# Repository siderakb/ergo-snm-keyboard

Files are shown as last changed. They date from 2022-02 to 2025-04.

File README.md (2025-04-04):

# ErgoSNM Keyboard







*ErgoSNM* \- a split ergonomic keyboard integrated with a trackball, designed to encourage people to leave their mouse behind.

- 64 keys in total.
    - Left half 29 + 6 keys.
    - Right half 29 keys + trackball.
- Cherry MX style switches, hot-swap available.
- USB Type-C.
- Column-staggered layout.
- The trackball can replace all mouse operations, allowing your right hand to stay on the *home row*.
    - Cursor movement and scrolling.
    - With the Combos feature:
        - *J*+*K* performs the left click
        - *K*+*L* performs the right click
        - *J*+*L* performs the middle click.

Introduction Video:

<a href="https://youtu.be/mWoAi_D721U" target="_blank">
  Thumbnail
</a>

| Rev | MCU | Note | Video |
| ----- | --- | --- | --- |
| `1.x` | Pro Micro (ATmega32U4) | Experimental version | |
| `2.x` | RaspberryPi **RP2040** | The first version suitable for daily use | [demo](https://youtu.be/1BXKdrCFn6c) |
| `3.x` | Nordic **nRF52840** (E73) | First wireless experimental version | [demo](https://www.youtube.com/watch?v=TtJiaOGiEaQ) |
| `4.x` | ??? | ⚡In progress | |

Build guide and more information can be found in the [📖Docs](https://siderakb.ziteh.dev/docs/ergosnm/intro)

## Clone

```bash
git clone --recurse-submodules https://github.com/siderakb/ergo-snm-keyboard.git
```

If `key-switches.pretty` folder is empty, run:

```bash
git submodule update --init --recursive
```

## Firmware

- Vial QMK: [siderakb/vial-qmk](https://github.com/siderakb/vial-qmk/tree/siderakb/main/keyboards/siderakb/ergosnm) (*siderakb/main* branch)
- nRF: [siderakb/ergo-snm-nrf-firmware](https://github.com/siderakb/ergo-snm-nrf-firmware)

## License

Hardware available under the [CERN-OHL-P v2](/LICENSE) permissive license.

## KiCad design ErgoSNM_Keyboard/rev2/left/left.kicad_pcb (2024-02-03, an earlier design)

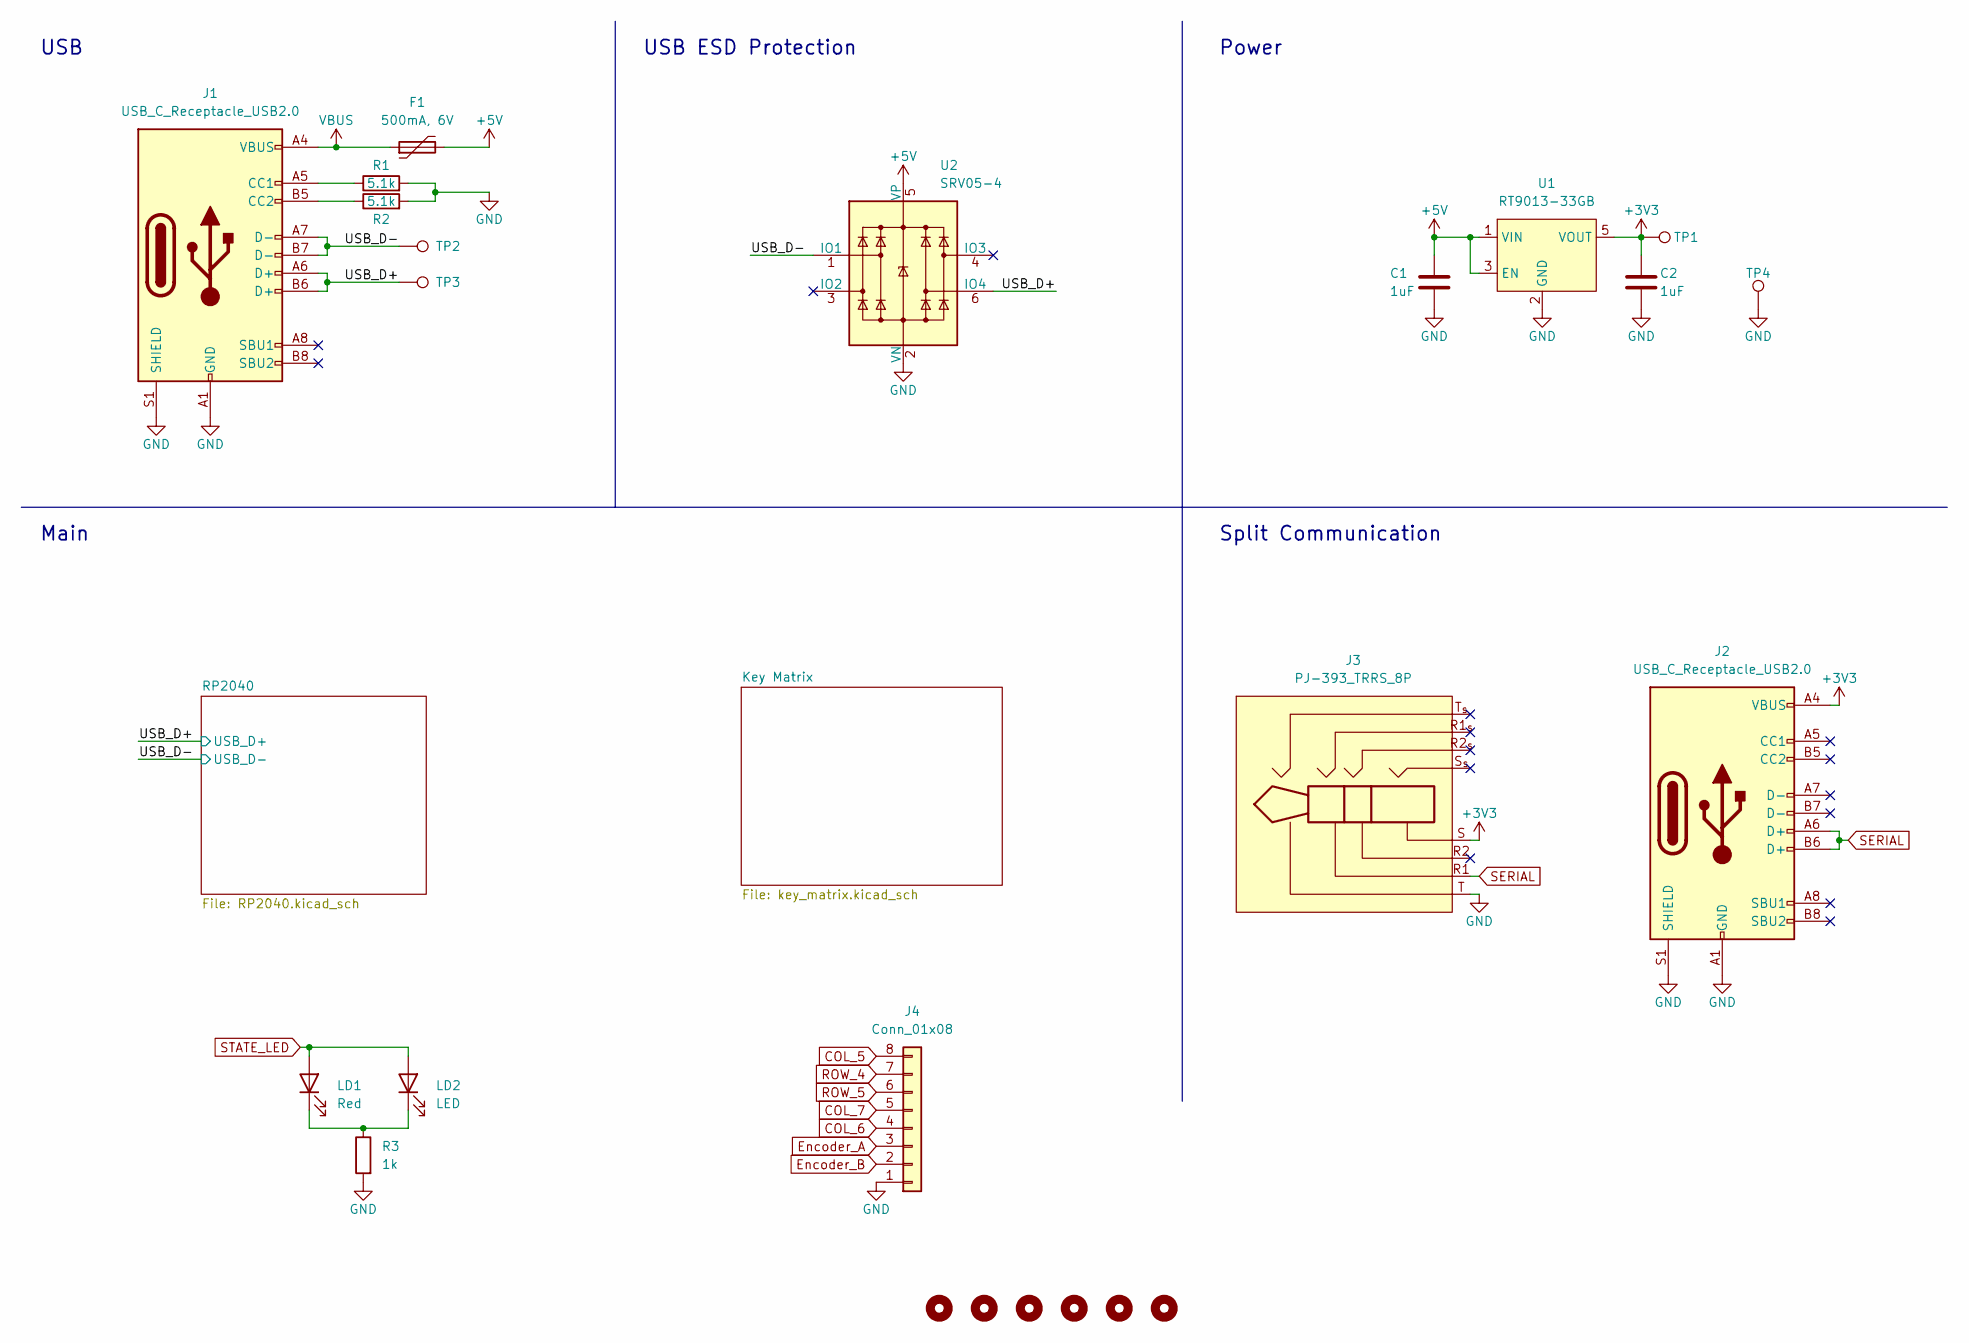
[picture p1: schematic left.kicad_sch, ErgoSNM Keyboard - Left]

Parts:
C1, C2: 1uF; C_0402_1005Metric; MFR. Part # CL05A105KA5NQNC; LCSC C52923
F1: 500mA, 6V; Fuse_0805_2012Metric; MFR. Part # SMD0805B050TF; LCSC C269104
H1, H2, H3, H4, H5, H6: MountingHole; MountingHole_2.2mm_M2
J1, J2: USB_C_Receptacle_USB2.0; USB_C_Receptacle_HRO_TYPE-C-31-M-12; MFR. Part # TYPE-C-31-M-12; LCSC C165948
J3: PJ-393_TRRS_8P; PJ-393 8P TRRS; MFR. Part # PJ-393 8PJ; LCSC C668609
J4: Conn_01x08; FPC_8P_0.5mm_AFC01-S08FCA-00; MFR. Part # SM08B-GHS-TB(LF)(SN); LCSC C265111
LD1: Red; LED_0603_1608Metric; MFR. Part # KT-0603R; LCSC C2286
LD2: LED; LED_0805_2012Metric_Pad1.15x1.40mm_HandSolder
R1, R2: 5.1k; R_0402_1005Metric; MFR. Part # 0402WGF5101TCE; LCSC C25905
R3: 1k; R_0402_1005Metric; MFR. Part # 0402WGF1001TCE; LCSC C11702
TP1, TP4: TestPoint; TestPoint_Pad_D2.5mm
TP2, TP3: TestPoint; TestPoint_Pad_D2.0mm
U1: RT9013-33GB; SOT-23-5; MFR. Part # RT9013-33GB; LCSC C47773
U2: SRV05-4; SOT-23-6; MFR. Part # SRV05-4-P-T7; LCSC C85364

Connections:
+3V3: C2.1, J2.A4 (VBUS), J2.A9 (VBUS), J2.B4 (VBUS), J2.B9 (VBUS), J3.S, TP1.1, U1.5 (VOUT); also elsewhere on the board
+5V: C1.1, F1.2, U1.1 (VIN), U1.3 (EN), U2.5 (VP)
/USB_D+: J1.A6 (D+), J1.B6 (D+), TP3.1, U2.6 (IO4); also elsewhere on the board
/USB_D-: J1.A7 (D-), J1.B7 (D-), TP2.1, U2.1 (IO1); also elsewhere on the board
COL_5: J4.8; also elsewhere on the board
COL_6: J4.4; also elsewhere on the board
COL_7: J4.5; also elsewhere on the board
Encoder_A: J4.3; also elsewhere on the board
Encoder_B: J4.2; also elsewhere on the board
GND: C1.2, C2.2, J1.A1 (GND), J1.A12 (GND), J1.B1 (GND), J1.B12 (GND), J1.S1 (SHIELD), J2.A1 (GND), J2.A12 (GND), J2.B1 (GND), J2.B12 (GND), J2.S1 (SHIELD), J3.T, J4.1, R1.2, R2.2, R3.2, TP4.1, U1.2 (GND), U2.2 (VN); also elsewhere on the board
unnamed: J1.A5 (CC1), R1.1
unnamed: J1.B5 (CC2), R2.1
unnamed: LD1.1 (K), LD2.1 (K), R3.1
ROW_4: J4.7; also elsewhere on the board
ROW_5: J4.6; also elsewhere on the board
SERIAL: J2.A6 (D+), J2.B6 (D+), J3.R1; also elsewhere on the board
STATE_LED: LD1.2 (A), LD2.2 (A); also elsewhere on the board
VBUS: F1.1, J1.A4 (VBUS), J1.A9 (VBUS), J1.B4 (VBUS), J1.B9 (VBUS)

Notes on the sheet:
Split Communication
USB ESD Protection
USB
Main
Power

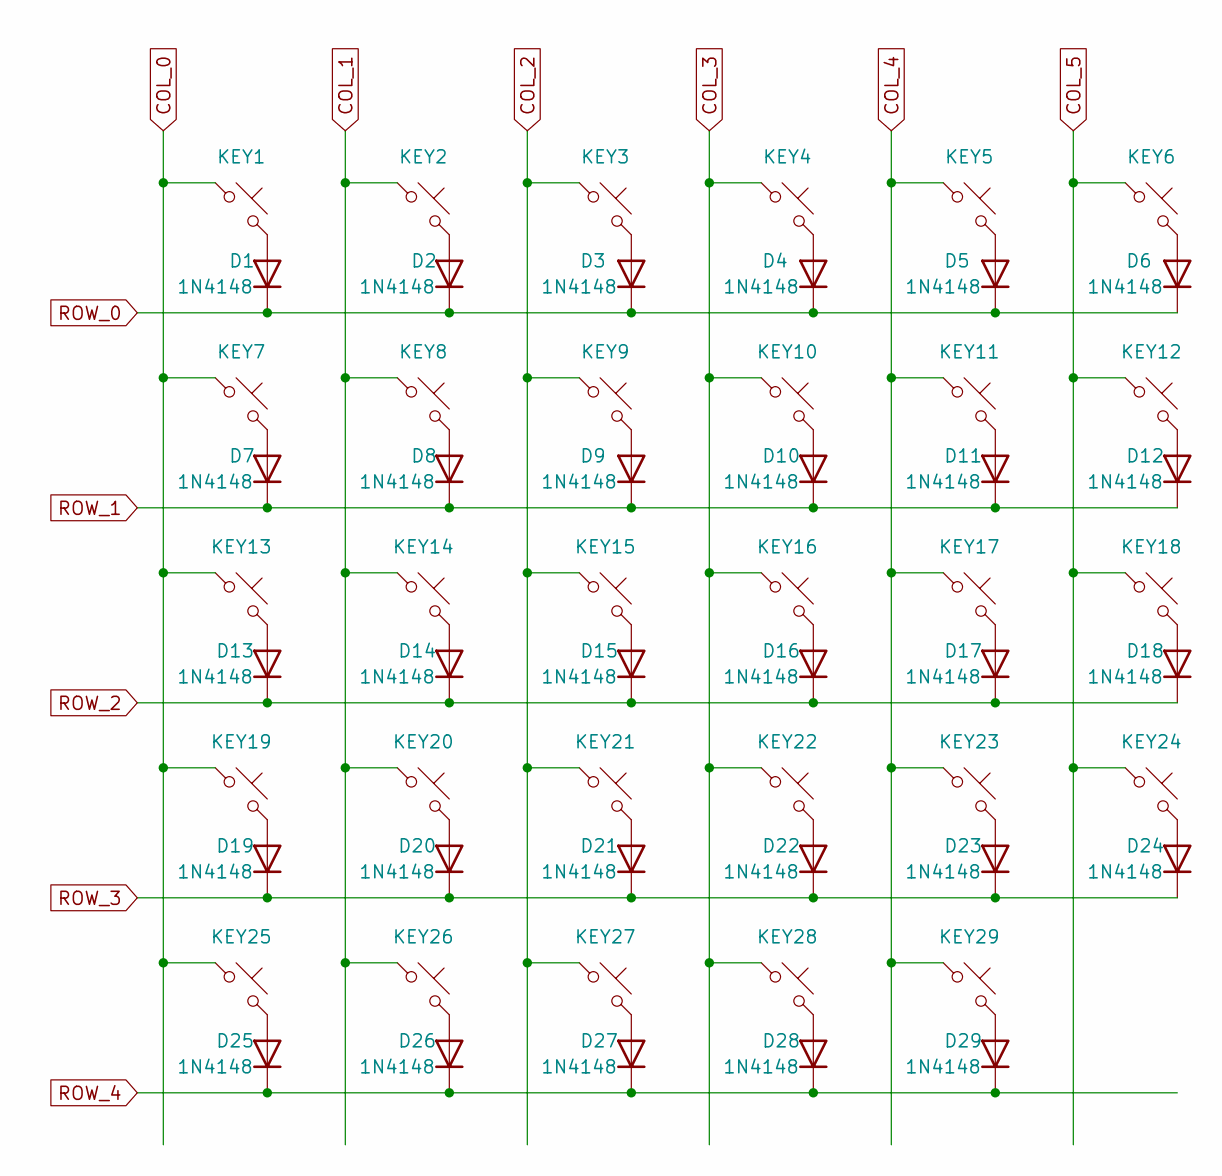
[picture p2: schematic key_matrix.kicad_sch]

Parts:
D1, D2, D3, D4, D5, D6, D7, D8, D9, D10, D11, D12, D13, D14, D15, D16, D17, D18, D19, D20, D21, D22, D23, D24, D25, D26, D27, D28, D29: 1N4148; D_SOD-123; MFR. Part # 1N4148W; LCSC C81598
KEY1, KEY2, KEY3, KEY4, KEY5, KEY6, KEY7, KEY8, KEY9, KEY10, KEY11, KEY12, KEY13, KEY14, KEY15, KEY16, KEY17, KEY18, KEY19, KEY20, KEY21, KEY22, KEY23, KEY24, KEY25, KEY26, KEY27, KEY28, KEY29: SW_Push_45deg; MX_switch_PTH_hotswap_A

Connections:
COL_0: KEY1.1, KEY7.1, KEY13.1, KEY19.1, KEY25.1; also elsewhere on the board
COL_1: KEY2.1, KEY8.1, KEY14.1, KEY20.1, KEY26.1; also elsewhere on the board
COL_2: KEY3.1, KEY9.1, KEY15.1, KEY21.1, KEY27.1; also elsewhere on the board
COL_3: KEY4.1, KEY10.1, KEY16.1, KEY22.1, KEY28.1; also elsewhere on the board
COL_4: KEY5.1, KEY11.1, KEY17.1, KEY23.1, KEY29.1; also elsewhere on the board
COL_5: KEY6.1, KEY12.1, KEY18.1, KEY24.1; also elsewhere on the board
unnamed: D1.2 (A), KEY1.2
unnamed: D2.2 (A), KEY2.2
unnamed: D3.2 (A), KEY3.2
unnamed: D4.2 (A), KEY4.2
unnamed: D5.2 (A), KEY5.2
unnamed: D6.2 (A), KEY6.2
unnamed: D7.2 (A), KEY7.2
unnamed: D8.2 (A), KEY8.2
unnamed: D9.2 (A), KEY9.2
unnamed: D10.2 (A), KEY10.2
unnamed: D11.2 (A), KEY11.2
unnamed: D12.2 (A), KEY12.2
unnamed: D13.2 (A), KEY13.2
unnamed: D14.2 (A), KEY14.2
unnamed: D15.2 (A), KEY15.2
unnamed: D16.2 (A), KEY16.2
unnamed: D17.2 (A), KEY17.2
unnamed: D18.2 (A), KEY18.2
unnamed: D19.2 (A), KEY19.2
unnamed: D20.2 (A), KEY20.2
unnamed: D21.2 (A), KEY21.2
unnamed: D22.2 (A), KEY22.2
unnamed: D23.2 (A), KEY23.2
unnamed: D24.2 (A), KEY24.2
unnamed: D25.2 (A), KEY25.2
unnamed: D26.2 (A), KEY26.2
unnamed: D27.2 (A), KEY27.2
unnamed: D28.2 (A), KEY28.2
unnamed: D29.2 (A), KEY29.2
ROW_0: D1.1 (K), D2.1 (K), D3.1 (K), D4.1 (K), D5.1 (K), D6.1 (K); also elsewhere on the board
ROW_1: D7.1 (K), D8.1 (K), D9.1 (K), D10.1 (K), D11.1 (K), D12.1 (K); also elsewhere on the board
ROW_2: D13.1 (K), D14.1 (K), D15.1 (K), D16.1 (K), D17.1 (K), D18.1 (K); also elsewhere on the board
ROW_3: D19.1 (K), D20.1 (K), D21.1 (K), D22.1 (K), D23.1 (K), D24.1 (K); also elsewhere on the board
ROW_4: D25.1 (K), D26.1 (K), D27.1 (K), D28.1 (K), D29.1 (K); also elsewhere on the board

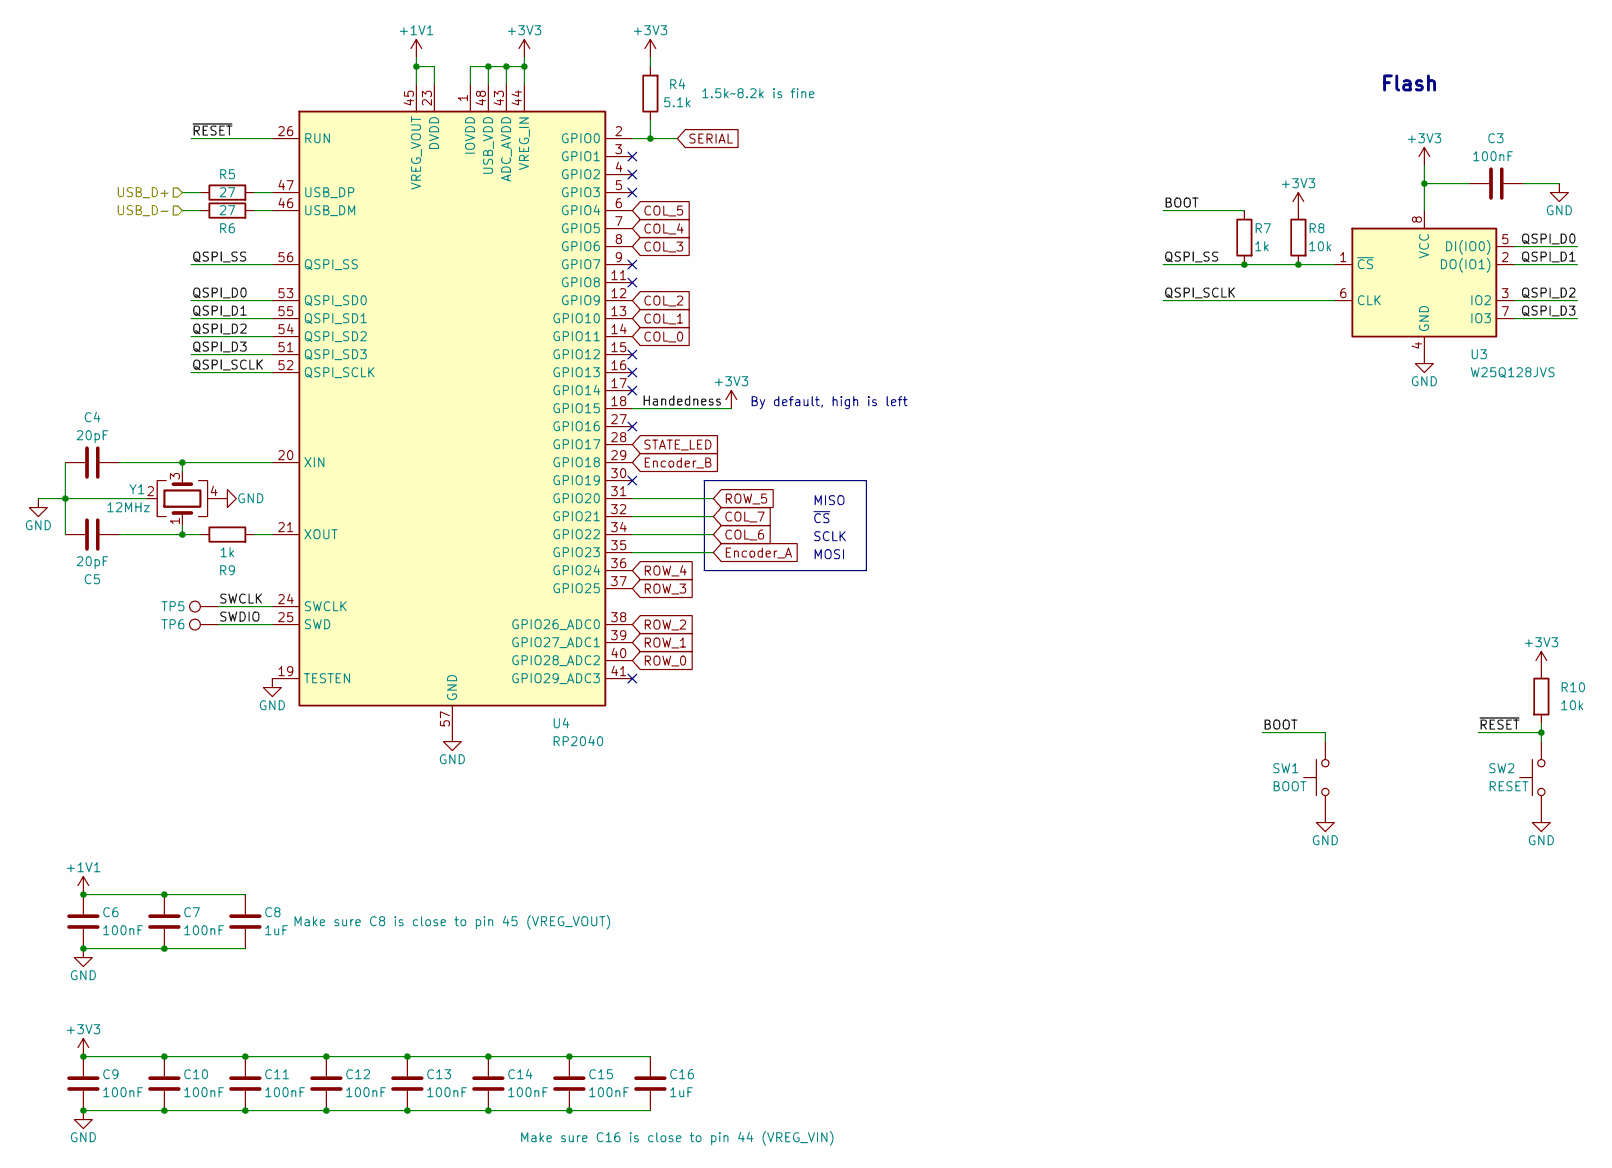
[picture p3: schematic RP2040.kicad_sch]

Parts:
C3, C6, C7, C9, C10, C11, C12, C13, C14, C15: 100nF; C_0402_1005Metric; MFR. Part # CL05B104KB54PNC; LCSC C307331
C4, C5: 20pF; C_0402_1005Metric; MFR. Part # 0402CG200J500NT; LCSC C1554
C8, C16: 1uF; C_0402_1005Metric; MFR. Part # CL05A105KA5NQNC; LCSC C52923
R4: 5.1k; R_0402_1005Metric; MFR. Part # 0402WGF5101TCE; LCSC C25905
R5, R6: 27; R_0603_1608Metric; MFR. Part # 0603WAF270JT5E; LCSC C25190
R7, R9: 1k; R_0402_1005Metric; MFR. Part # 0402WGF1001TCE; LCSC C11702
R8, R10: 10k; R_0402_1005Metric; MFR. Part # 0402WGF1002TCE; LCSC C25744
SW1: BOOT; SW_SPST_TL3342; MFR. Part # TS-1187A-B-A-B; LCSC C318884
SW2: RESET; SW_SPST_TL3342; MFR. Part # TS-1187A-B-A-B; LCSC C318884
TP5, TP6: TestPoint; TestPoint_Pad_D2.5mm
U3: W25Q128JVS; SOIC-8_5.23x5.23mm_P1.27mm; MFR. Part # W25Q128JVSIQ; LCSC C97521
U4: RP2040; QFN-56-1EP_7x7mm_P0.4mm_EP3.2x3.2mm; MFR. Part # RP2040; LCSC C2040
Y1: 12MHz; Crystal_SMD_3225-4Pin_3.2x2.5mm; MFR. Part # X322512MSB4SI; LCSC C9002

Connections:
+1V1: C6.1, C7.1, C8.1, U4.23 (DVDD), U4.45 (VREG_VOUT), U4.50 (DVDD)
+3V3: C3.1, C9.1, C10.1, C11.1, C12.1, C13.1, C14.1, C15.1, C16.1, R4.2, R8.1, R10.1, U3.8 (VCC), U4.1 (IOVDD), U4.10 (IOVDD), U4.18 (GPIO15), U4.22 (IOVDD), U4.33 (IOVDD), U4.42 (IOVDD), U4.43 (ADC_AVDD), U4.44 (VREG_IN), U4.48 (USB_VDD), U4.49 (IOVDD); also elsewhere on the board
/RP2040/BOOT: R7.1, SW1.2
/RP2040/QSPI_D0: U3.5 (DI(IO0)), U4.53 (QSPI_SD0)
/RP2040/QSPI_D1: U3.2 (DO(IO1)), U4.55 (QSPI_SD1)
/RP2040/QSPI_D2: U3.3 (IO2), U4.54 (QSPI_SD2)
/RP2040/QSPI_D3: U3.7 (IO3), U4.51 (QSPI_SD3)
/RP2040/QSPI_SCLK: U3.6 (CLK), U4.52 (QSPI_SCLK)
/RP2040/QSPI_SS: R7.2, R8.2, U3.1 (~CS), U4.56 (QSPI_SS)
/RP2040/SWCLK: TP5.1, U4.24 (SWCLK)
/RP2040/SWDIO: TP6.1, U4.25 (SWD)
/RP2040/~RESET: R10.2, SW2.2, U4.26 (RUN)
/USB_D+: R5.1; also elsewhere on the board
/USB_D-: R6.1; also elsewhere on the board
COL_0: U4.14 (GPIO11); also elsewhere on the board
COL_1: U4.13 (GPIO10); also elsewhere on the board
COL_2: U4.12 (GPIO9); also elsewhere on the board
COL_3: U4.8 (GPIO6); also elsewhere on the board
COL_4: U4.7 (GPIO5); also elsewhere on the board
COL_5: U4.6 (GPIO4); also elsewhere on the board
COL_6: U4.34 (GPIO22); also elsewhere on the board
COL_7: U4.32 (GPIO21); also elsewhere on the board
Encoder_A: U4.35 (GPIO23); also elsewhere on the board
Encoder_B: U4.29 (GPIO18); also elsewhere on the board
GND: C3.2, C4.1, C5.1, C6.2, C7.2, C8.2, C9.2, C10.2, C11.2, C12.2, C13.2, C14.2, C15.2, C16.2, SW1.1, SW2.1, U3.4 (GND), U4.19 (TESTEN), U4.57 (GND), Y1.2, Y1.4; also elsewhere on the board
unnamed: C4.2, U4.20 (XIN), Y1.3
unnamed: C5.2, R9.1, Y1.1
unnamed: R5.2, U4.47 (USB_DP)
unnamed: R6.2, U4.46 (USB_DM)
unnamed: R9.2, U4.21 (XOUT)
ROW_0: U4.40 (GPIO28_ADC2); also elsewhere on the board
ROW_1: U4.39 (GPIO27_ADC1); also elsewhere on the board
ROW_2: U4.38 (GPIO26_ADC0); also elsewhere on the board
ROW_3: U4.37 (GPIO25); also elsewhere on the board
ROW_4: U4.36 (GPIO24); also elsewhere on the board
ROW_5: U4.31 (GPIO20); also elsewhere on the board
SERIAL: R4.1, U4.2 (GPIO0); also elsewhere on the board
STATE_LED: U4.28 (GPIO17); also elsewhere on the board

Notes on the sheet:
~{CS}
Flash
SCLK
By default, high is left
MISO
MOSI

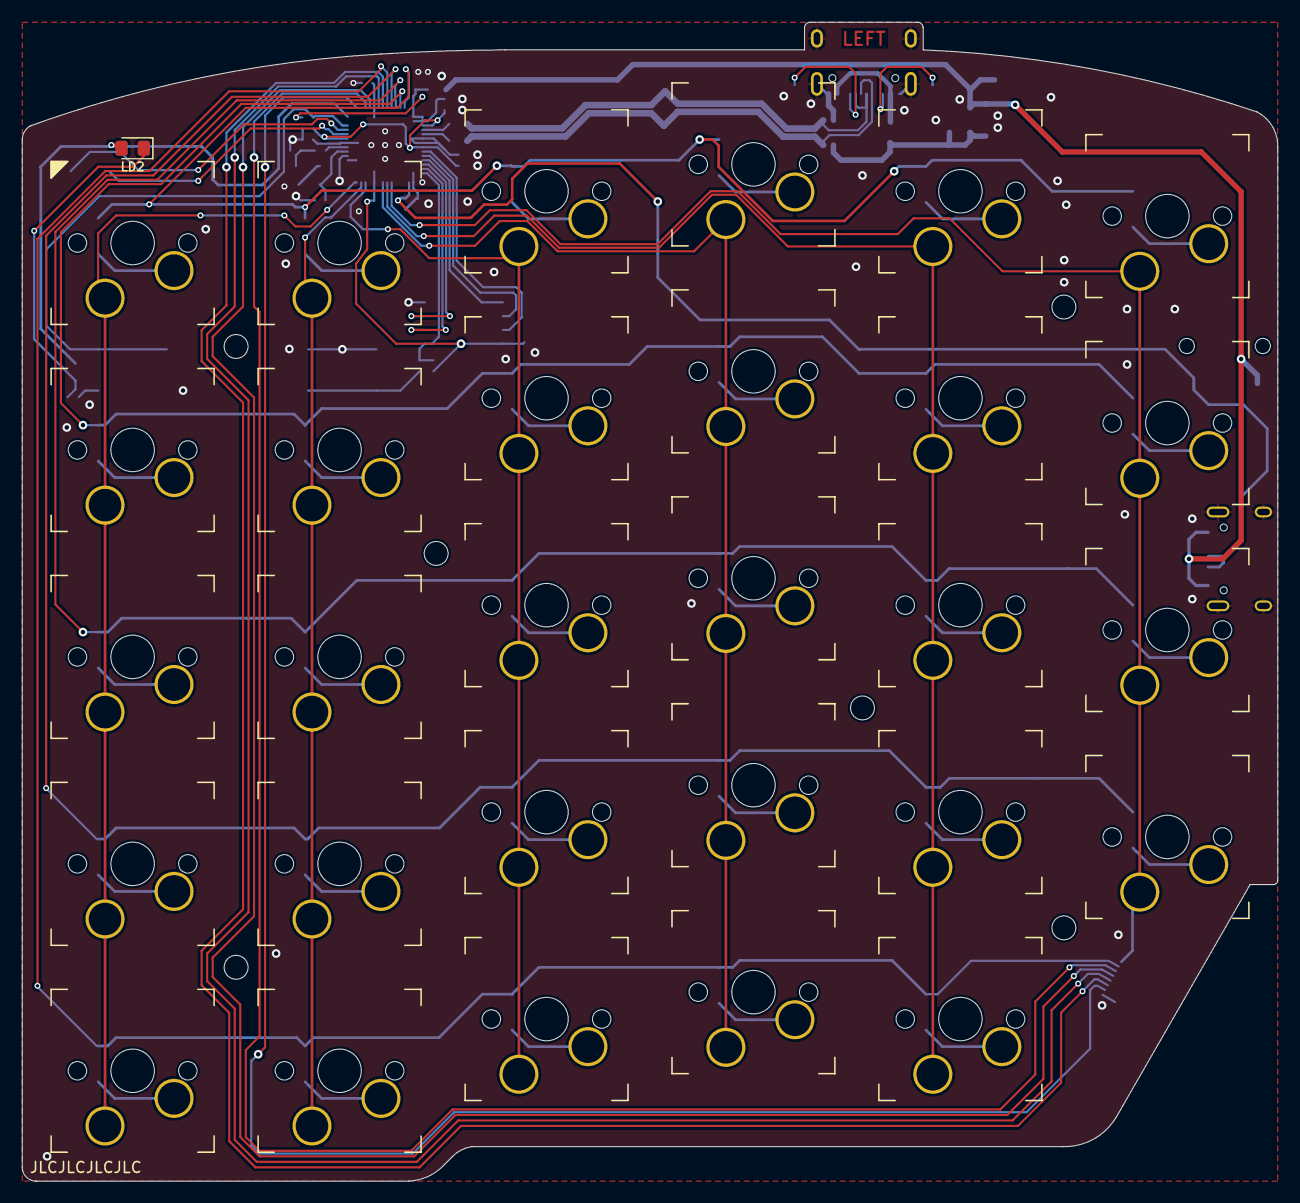
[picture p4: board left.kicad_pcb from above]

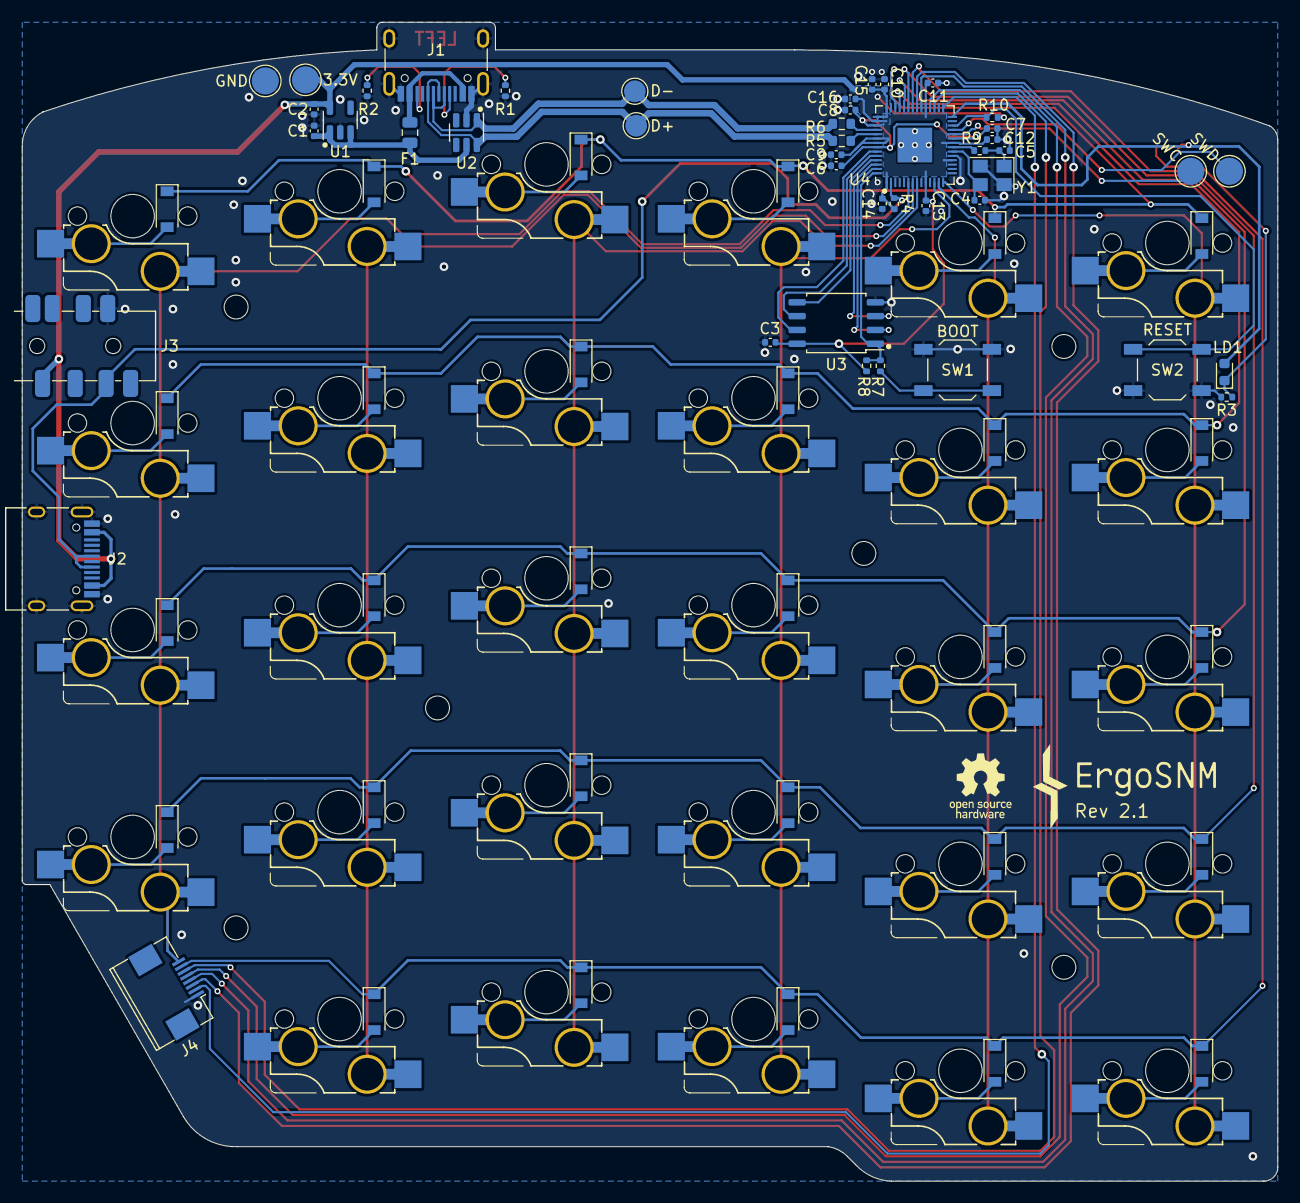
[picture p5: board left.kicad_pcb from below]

Board: 2 copper layers, 115.6 x 106.7 mm, 110 parts (80 on the bottom side), 72 nets.

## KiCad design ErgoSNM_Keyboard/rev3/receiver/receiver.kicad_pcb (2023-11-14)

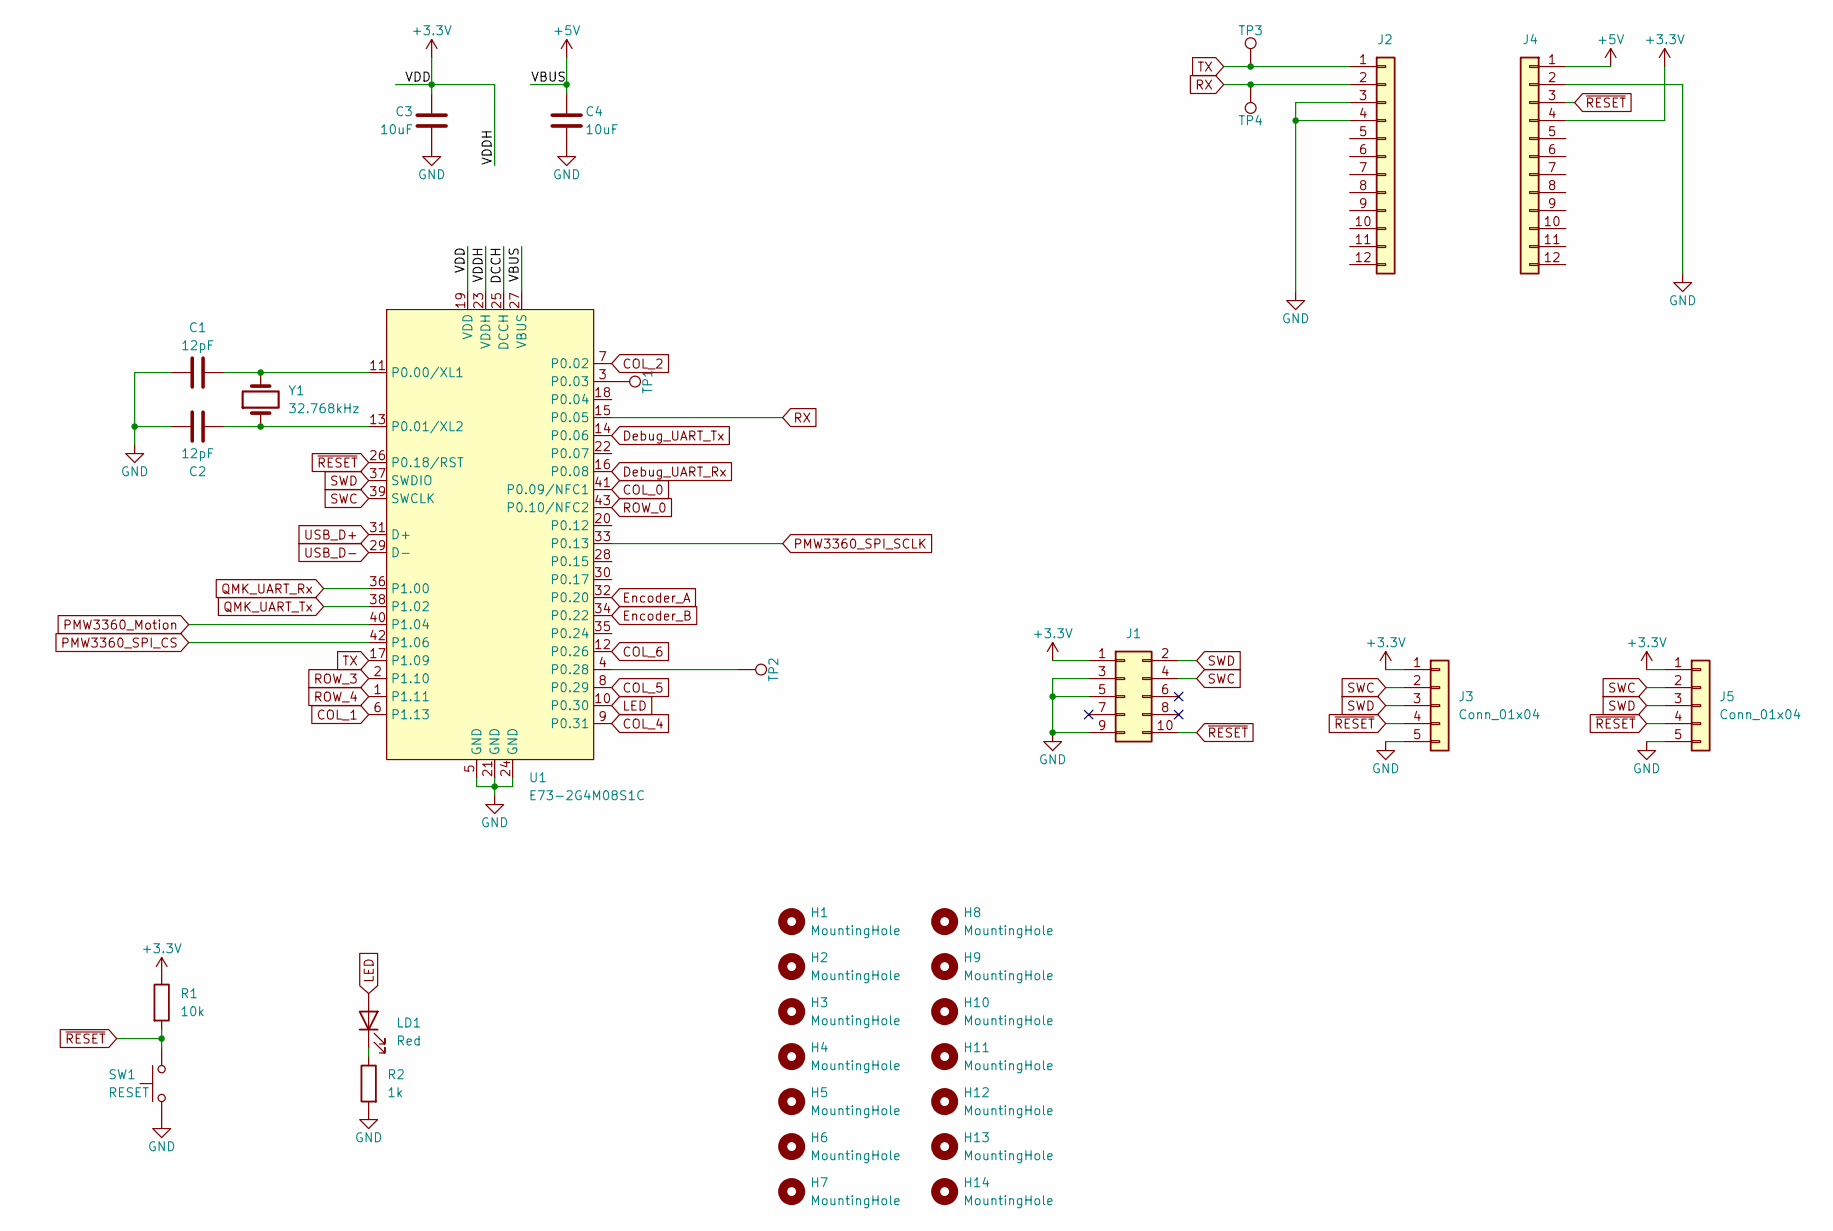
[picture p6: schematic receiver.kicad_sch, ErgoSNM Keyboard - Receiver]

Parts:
C1, C2: 12pF; C_0603_1608Metric
C3, C4: 10uF; C_0603_1608Metric
H1, H2, H3, H4, H5, H6, H7, H8, H9, H10, H11, H12, H13, H14: MountingHole; Mouse bite
J1: Conn_02x05_Counter_Clockwise; PinHeader_2x05_P1.27mm_Vertical
J2, J4: Conn_01x13; PinHeader_1x12_P2.54mm_Vertical
J3, J5: Conn_01x04; PinHeader_1x05_P2.54mm_Vertical
LD1: Red; LED_0603_1608Metric; MFR. Part # KT-0603R; LCSC C2286
R1: 10k; R_0603_1608Metric; MFR. Part # 0402WGF1002TCE; LCSC C25744
R2: 1k; R_0603_1608Metric; MFR. Part # 0402WGF1001TCE; LCSC C11702
SW1: RESET; SW_SPST_CK_RS282G05A3; MFR. Part # TS-1187A-B-A-B; LCSC C318884
TP1, TP2, TP3, TP4: TestPoint; TestPoint_Pad_D1.5mm
U1: E73-2G4M08S1C; E73-2G4M08S1C-52840
Y1: 32.768kHz; Crystal_SMD_3215-2Pin_3.2x1.5mm

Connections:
+3.3V: C3.1, J1.1, J3.1, J4.4, J5.1, R1.1, U1.19 (VDD), U1.23 (VDDH)
+5V: C4.1, J4.1, U1.27 (VBUS)
/DCCH: U1.25 (DCCH)
COL_0: U1.41 (P0.09/NFC1)
COL_1: U1.6 (P1.13)
COL_2: U1.7 (P0.02)
COL_4: U1.9 (P0.31)
COL_5: U1.8 (P0.29)
COL_6: U1.12 (P0.26)
Debug_UART_Rx: U1.16 (P0.08)
Debug_UART_Tx: U1.14 (P0.06)
Encoder_A: U1.32 (P0.20)
Encoder_B: U1.34 (P0.22)
GND: C1.2, C2.1, C3.2, C4.2, J1.3, J1.5, J1.9, J2.3, J2.4, J3.5, J4.2, J5.5, R2.2, SW1.1, U1.5 (GND), U1.21 (GND), U1.24 (GND)
LED: LD1.2 (A), U1.10 (P0.30)
unnamed: LD1.1 (K), R2.1
unnamed: C1.1, U1.11 (P0.00/XL1), Y1.2
unnamed: C2.2, U1.13 (P0.01/XL2), Y1.1
unnamed: TP1.1, U1.3 (P0.03)
unnamed: TP2.1, U1.4 (P0.28)
PMW3360_Motion: U1.40 (P1.04)
PMW3360_SPI_CS: U1.42 (P1.06)
PMW3360_SPI_SCLK: U1.33 (P0.13)
QMK_UART_Rx: U1.36 (P1.00)
QMK_UART_Tx: U1.38 (P1.02)
ROW_0: U1.43 (P0.10/NFC2)
ROW_3: U1.2 (P1.10)
ROW_4: U1.1 (P1.11)
RX: J2.2, TP4.1, U1.15 (P0.05)
SWC: J1.4, J3.2, J5.2, U1.39 (SWCLK)
SWD: J1.2, J3.3, J5.3, U1.37 (SWDIO)
TX: J2.1, TP3.1, U1.17 (P1.09)
USB_D+: U1.31 (D+)
USB_D-: U1.29 (D-)
~RESET: J1.10, J3.4, J4.3, J5.4, R1.2, SW1.2, U1.26 (P0.18/RST)

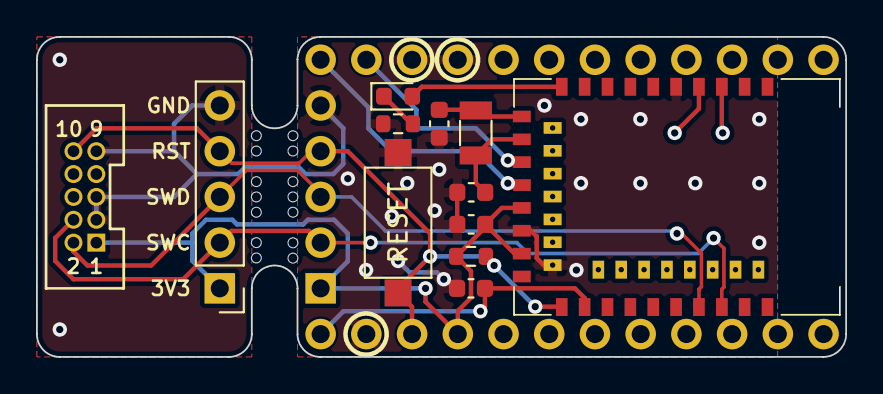
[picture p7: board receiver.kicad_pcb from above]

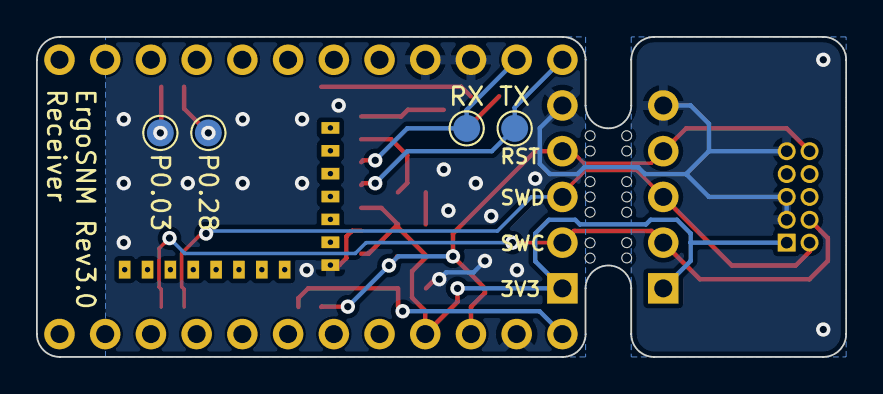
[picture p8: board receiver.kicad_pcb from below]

Board: 2 copper layers, 45.0 x 17.8 mm, 33 parts (6 on the bottom side), 14 nets.

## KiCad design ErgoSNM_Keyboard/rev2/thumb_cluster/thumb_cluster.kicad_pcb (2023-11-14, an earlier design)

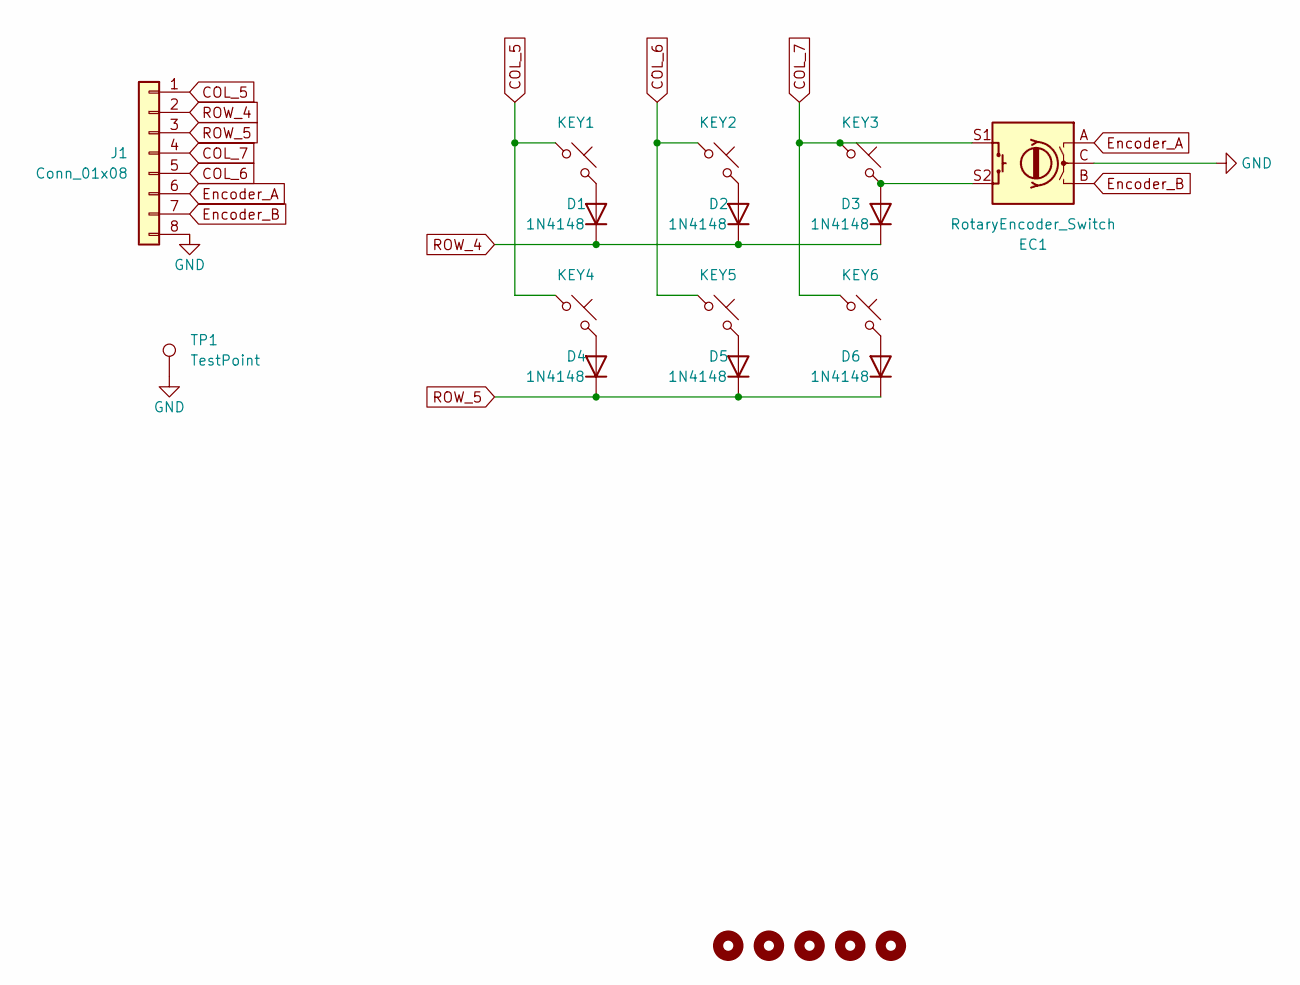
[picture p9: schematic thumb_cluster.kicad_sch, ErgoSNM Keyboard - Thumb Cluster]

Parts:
D1, D2, D3, D4, D5, D6: 1N4148; D_SOD-123; MFR. Part # 1N4148W; LCSC C81598
EC1: RotaryEncoder_Switch; RotaryEncoder_Alps_EC11E-Switch_Vertical_H20mm
H1, H2, H3, H4, H5: MountingHole; MountingHole_2.2mm_M2
J1: Conn_01x08; FPC_8P_0.5mm_AFC01-S08FCA-00; MFR. Part # SM08B-GHS-TB(LF)(SN); LCSC C265111
KEY1, KEY2, KEY3, KEY4, KEY5, KEY6: SW_Push_45deg; MX_switch_PTH_hotswap_A
TP1: TestPoint; TestPoint_Pad_D2.5mm

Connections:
COL_5: J1.1, KEY1.1, KEY4.1
COL_6: J1.5, KEY2.1, KEY5.1
COL_7: EC1.S1, J1.4, KEY3.1, KEY6.1
Encoder_A: EC1.A, J1.6
Encoder_B: EC1.B, J1.7
GND: EC1.C, J1.8, TP1.1
unnamed: D1.2 (A), KEY1.2
unnamed: D2.2 (A), KEY2.2
unnamed: D3.2 (A), EC1.S2, KEY3.2
unnamed: D4.2 (A), KEY4.2
unnamed: D5.2 (A), KEY5.2
unnamed: D6.2 (A), KEY6.2
ROW_4: D1.1 (K), D2.1 (K), D3.1 (K), J1.2
ROW_5: D4.1 (K), D5.1 (K), D6.1 (K), J1.3

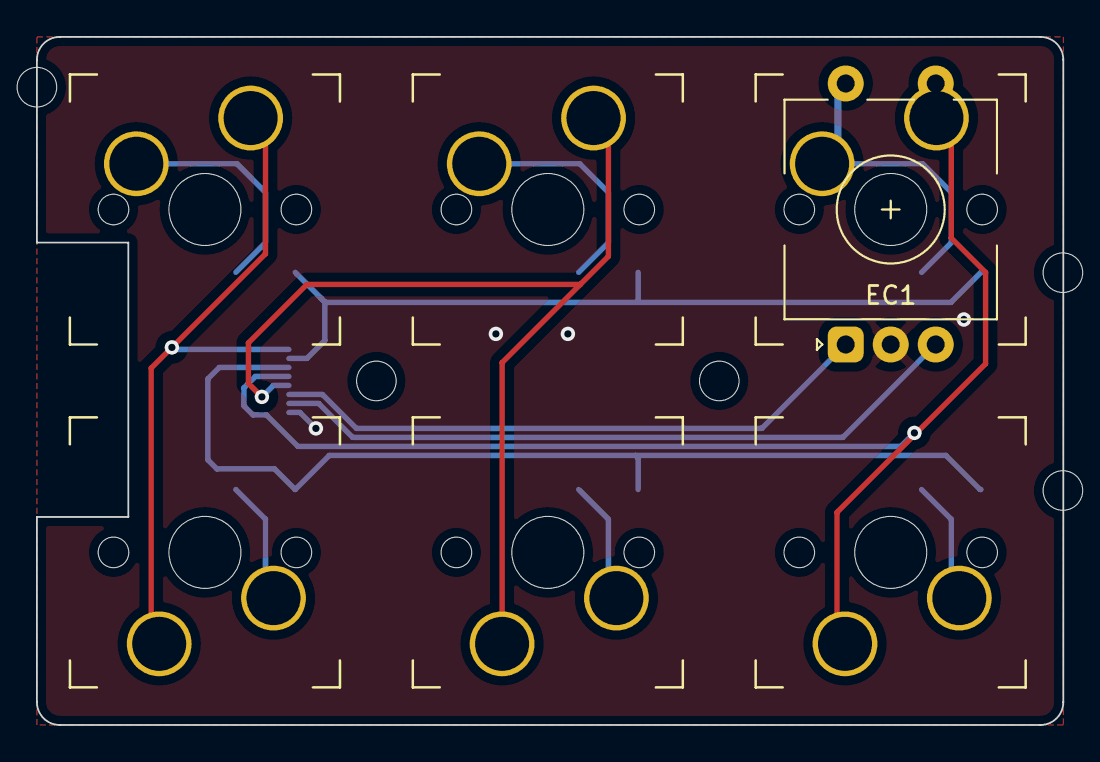
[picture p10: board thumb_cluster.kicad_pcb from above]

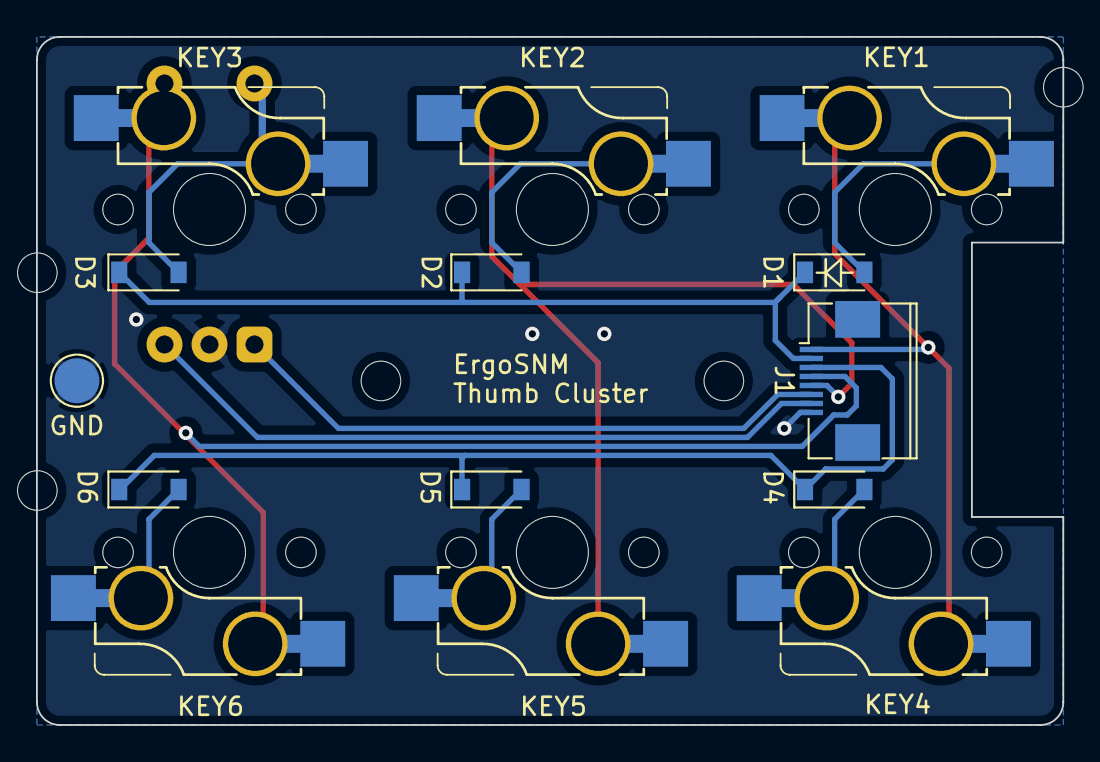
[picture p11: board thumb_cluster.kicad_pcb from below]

Board: 2 copper layers, 57.0 x 38.2 mm, 20 parts (8 on the bottom side), 14 nets.

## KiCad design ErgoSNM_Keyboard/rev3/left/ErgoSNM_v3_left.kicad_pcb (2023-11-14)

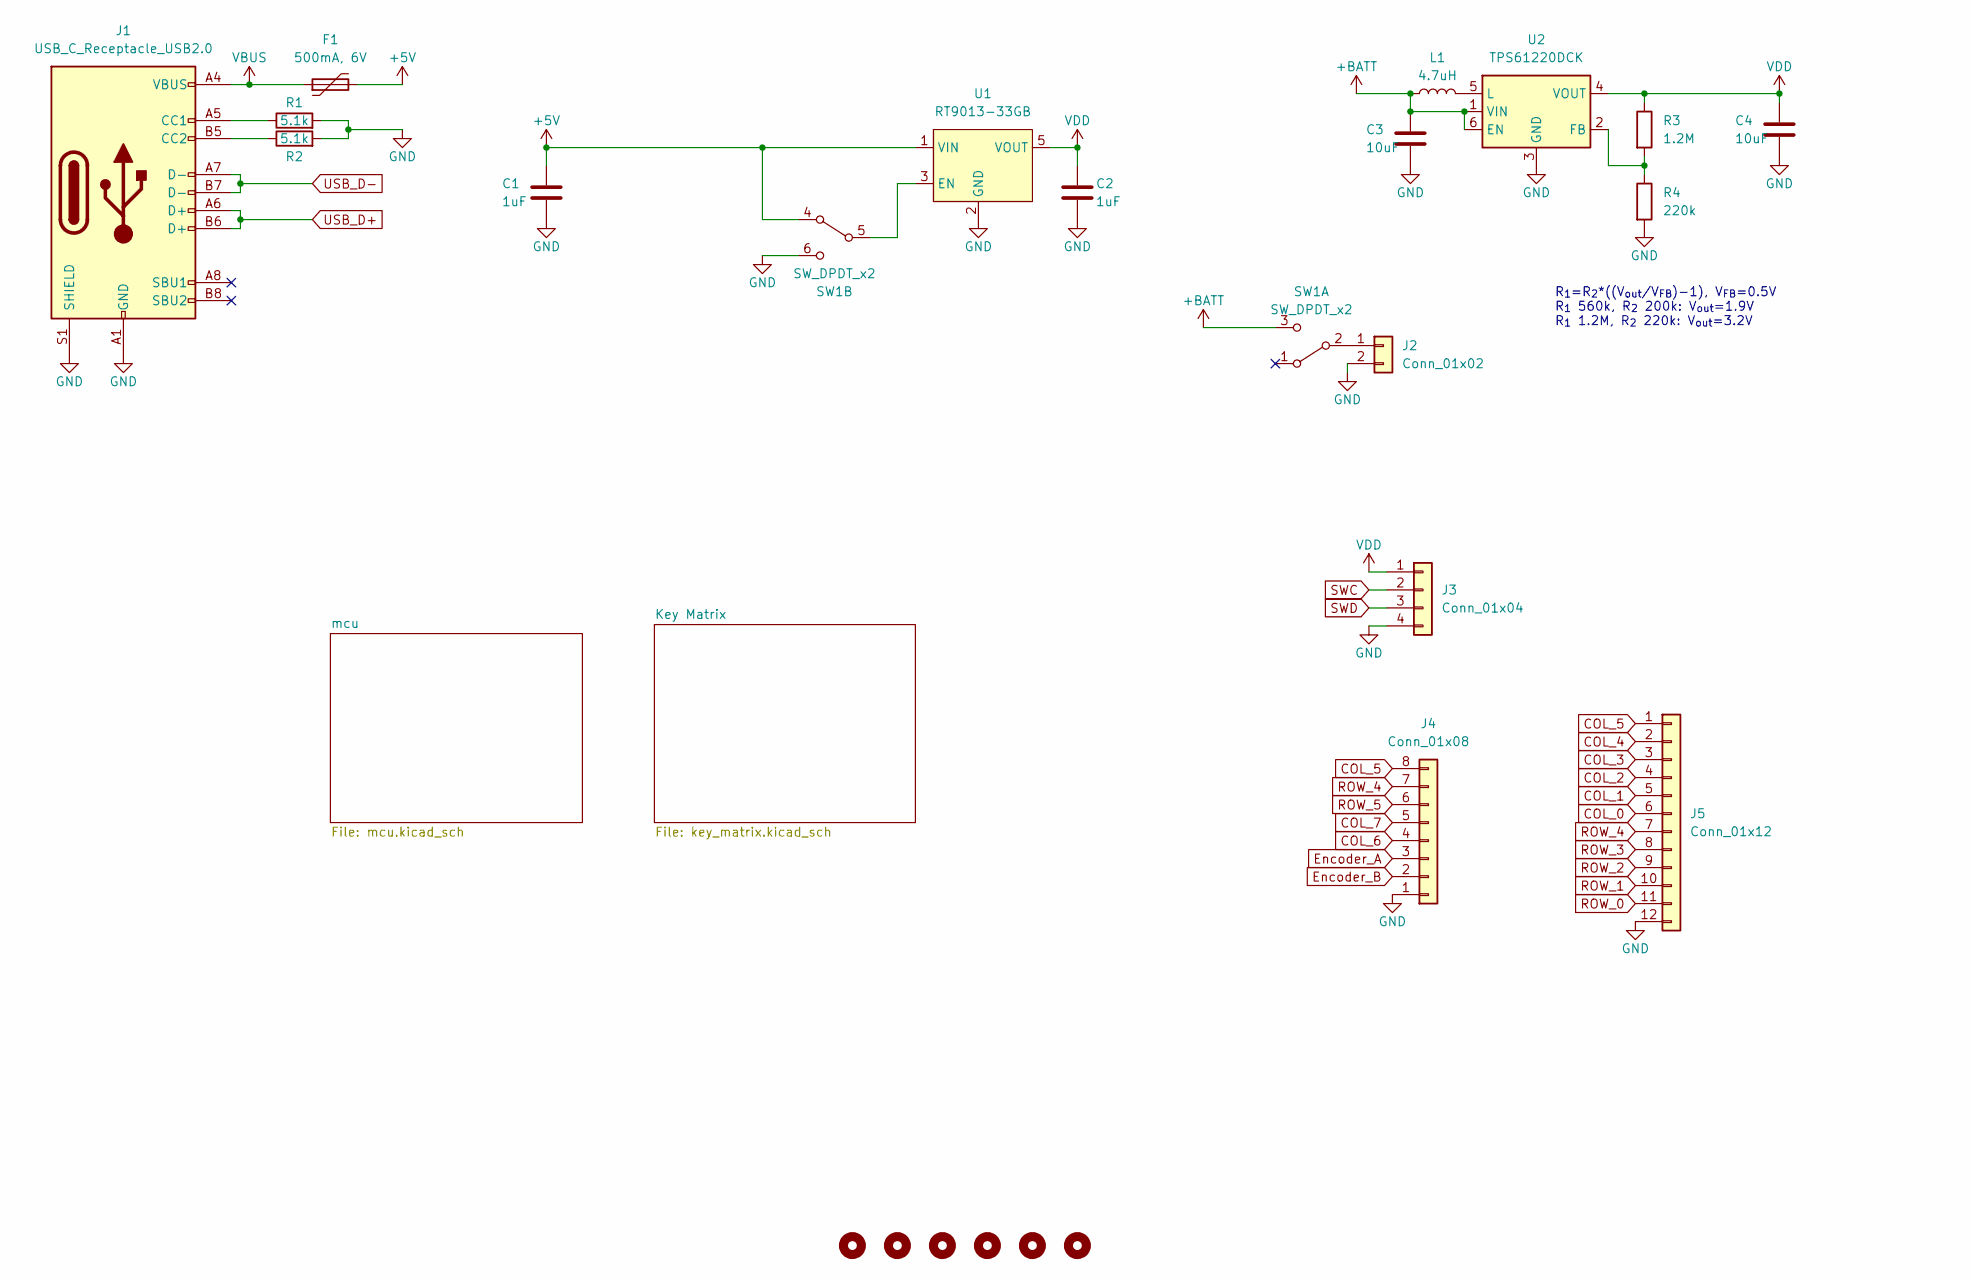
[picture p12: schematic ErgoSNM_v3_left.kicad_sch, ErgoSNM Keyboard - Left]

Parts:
C1, C2: 1uF; C_0603_1608Metric; MFR. Part # CL05A105KA5NQNC; LCSC C52923
C3, C4: 10uF; C_0603_1608Metric; MFR. Part # CL05A105KA5NQNC; LCSC C52923
F1: 500mA, 6V; Fuse_0805_2012Metric; MFR. Part # SMD0805B050TF; LCSC C269104
H1, H2, H3, H4, H5, H6: MountingHole; MountingHole_2.2mm_M2
J1: USB_C_Receptacle_USB2.0; USB_C_Receptacle_HRO_TYPE-C-31-M-12; MFR. Part # TYPE-C-31-M-12; LCSC C165948
J2: Conn_01x02; PinHeader_1x02_P2.54mm_Vertical
J3: Conn_01x04; PinHeader_1x04_P2.54mm_Vertical
J4: Conn_01x08; FPC_8P_0.5mm_AFC01-S08FCA-00; MFR. Part # SM08B-GHS-TB(LF)(SN); LCSC C265111
J5: Conn_01x12; PinHeader_1x12_P2.54mm_Vertical
L1: 4.7uH; L_Changjiang_FNR4030S
R1, R2: 5.1k; R_0603_1608Metric; MFR. Part # 0402WGF5101TCE; LCSC C25905
R3: 1.2M; R_0603_1608Metric; MFR. Part # 0402WGF1002TCE; LCSC C25744
R4: 220k; R_0603_1608Metric; MFR. Part # 0402WGF1002TCE; LCSC C25744
SW1: SW_DPDT_x2; MSKT-22D14-T
U1: RT9013-33GB; SOT-23-5; MFR. Part # RT9013-33GB; LCSC C47773
U2: TPS61220DCK; Texas_R-PDSO-G6

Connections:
+5V: C1.1, F1.2, SW1.4 (A), U1.1 (VIN); also elsewhere on the board
+BATT: C3.1, L1.1, SW1.3 (C), U2.1 (VIN), U2.6 (EN)
COL_0: J5.6; also elsewhere on the board
COL_1: J5.5; also elsewhere on the board
COL_2: J5.4; also elsewhere on the board
COL_3: J5.3; also elsewhere on the board
COL_4: J5.2; also elsewhere on the board
COL_5: J4.8, J5.1; also elsewhere on the board
COL_6: J4.4; also elsewhere on the board
COL_7: J4.5; also elsewhere on the board
Encoder_A: J4.3; also elsewhere on the board
Encoder_B: J4.2; also elsewhere on the board
GND: C1.2, C2.2, C3.2, C4.2, J1.A1 (GND), J1.A12 (GND), J1.B1 (GND), J1.B12 (GND), J1.S1 (SHIELD), J2.2, J3.4, J4.1, J5.12, R1.2, R2.2, R4.2, SW1.6 (C), U1.2 (GND), U2.3 (GND); also elsewhere on the board
unnamed: J1.A5 (CC1), R1.1
unnamed: J1.B5 (CC2), R2.1
unnamed: J2.1, SW1.2 (B)
unnamed: SW1.5 (B), U1.3 (EN)
unnamed: R3.2, R4.1, U2.2 (FB)
unnamed: L1.2, U2.5 (L)
ROW_0: J5.11; also elsewhere on the board
ROW_1: J5.10; also elsewhere on the board
ROW_2: J5.9; also elsewhere on the board
ROW_3: J5.8; also elsewhere on the board
ROW_4: J4.7, J5.7; also elsewhere on the board
ROW_5: J4.6; also elsewhere on the board
SWC: J3.2; also elsewhere on the board
SWD: J3.3; also elsewhere on the board
USB_D+: J1.A6 (D+), J1.B6 (D+); also elsewhere on the board
USB_D-: J1.A7 (D-), J1.B7 (D-); also elsewhere on the board
VBUS: F1.1, J1.A4 (VBUS), J1.A9 (VBUS), J1.B4 (VBUS), J1.B9 (VBUS)
VDD: C2.1, C4.1, J3.1, R3.1, U1.5 (VOUT), U2.4 (VOUT); also elsewhere on the board

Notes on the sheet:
R_{1}=R_{2}*((V_{out}/V_{FB})-1), V_{FB}=0.5V R_{1} 560k, R_{2} 200k: V_{out}=1.9V R_{1} 1.2M, R_{2} 220k: V_{out}=3.2V


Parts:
D1, D2, D3, D4, D5, D6, D7, D8, D9, D10, D11, D12, D13, D14, D15, D16, D17, D18, D19, D20, D21, D22, D23, D24, D25, D26, D27, D28, D29: 1N4148; D_SOD-123; MFR. Part # 1N4148W; LCSC C81598
KEY1, KEY2, KEY3, KEY4, KEY5, KEY6, KEY7, KEY8, KEY9, KEY10, KEY11, KEY12, KEY13, KEY14, KEY15, KEY16, KEY17, KEY18, KEY19, KEY20, KEY21, KEY22, KEY23, KEY24, KEY25, KEY26, KEY27, KEY28, KEY29: SW_Push_45deg; SW_MX_HotSwap_PTH

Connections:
COL_0: KEY1.2, KEY2.2, KEY3.2, KEY4.2, KEY5.2; also elsewhere on the board
COL_1: KEY6.2, KEY7.2, KEY8.2, KEY9.2, KEY10.2; also elsewhere on the board
COL_2: KEY11.2, KEY12.2, KEY13.2, KEY14.2, KEY15.2; also elsewhere on the board
COL_3: KEY16.2, KEY17.2, KEY18.2, KEY19.2, KEY20.2; also elsewhere on the board
COL_4: KEY21.2, KEY22.2, KEY23.2, KEY24.2, KEY25.2; also elsewhere on the board
COL_5: KEY26.2, KEY27.2, KEY28.2, KEY29.2; also elsewhere on the board
unnamed: D1.2 (A), KEY1.1
unnamed: D2.2 (A), KEY2.1
unnamed: D3.2 (A), KEY3.1
unnamed: D4.2 (A), KEY4.1
unnamed: D5.2 (A), KEY5.1
unnamed: D6.2 (A), KEY6.1
unnamed: D7.2 (A), KEY7.1
unnamed: D8.2 (A), KEY8.1
unnamed: D9.2 (A), KEY9.1
unnamed: D10.2 (A), KEY10.1
unnamed: D11.2 (A), KEY11.1
unnamed: D12.2 (A), KEY12.1
unnamed: D13.2 (A), KEY13.1
unnamed: D14.2 (A), KEY14.1
unnamed: D15.2 (A), KEY15.1
unnamed: D16.2 (A), KEY16.1
unnamed: D17.2 (A), KEY17.1
unnamed: D18.2 (A), KEY18.1
unnamed: D19.2 (A), KEY19.1
unnamed: D20.2 (A), KEY20.1
unnamed: D21.2 (A), KEY21.1
unnamed: D22.2 (A), KEY22.1
unnamed: D23.2 (A), KEY23.1
unnamed: D24.2 (A), KEY24.1
unnamed: D25.2 (A), KEY25.1
unnamed: D26.2 (A), KEY26.1
unnamed: D27.2 (A), KEY27.1
unnamed: D28.2 (A), KEY28.1
unnamed: D29.2 (A), KEY29.1
ROW_0: D1.1 (K), D6.1 (K), D11.1 (K), D16.1 (K), D21.1 (K), D26.1 (K); also elsewhere on the board
ROW_1: D2.1 (K), D7.1 (K), D12.1 (K), D17.1 (K), D22.1 (K), D27.1 (K); also elsewhere on the board
ROW_2: D3.1 (K), D8.1 (K), D13.1 (K), D18.1 (K), D23.1 (K), D28.1 (K); also elsewhere on the board
ROW_3: D4.1 (K), D9.1 (K), D14.1 (K), D19.1 (K), D24.1 (K), D29.1 (K); also elsewhere on the board
ROW_4: D5.1 (K), D10.1 (K), D15.1 (K), D20.1 (K), D25.1 (K); also elsewhere on the board


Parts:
C5, C6: 12pF; C_0603_1608Metric
C7, C8: 10uF; C_0603_1608Metric
R5: 10k; R_0603_1608Metric; MFR. Part # 0402WGF1002TCE; LCSC C25744
SW2: RESET; SW_SPST_TL3342; MFR. Part # TS-1187A-B-A-B; LCSC C318884
U3: E73-2G4M08S1C; E73-2G4M08S1C-52840
Y1: 32.768kHz; Crystal_SMD_3215-2Pin_3.2x1.5mm

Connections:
+5V: C8.1, U3.27 (VBUS); also elsewhere on the board
/mcu/DCCH: U3.25 (DCCH)
COL_0: U3.43 (P0.10/NFC2); also elsewhere on the board
COL_1: U3.41 (P0.09/NFC1); also elsewhere on the board
COL_2: U3.1 (P1.11); also elsewhere on the board
COL_3: U3.2 (P1.10); also elsewhere on the board
COL_4: U3.3 (P0.03); also elsewhere on the board
COL_5: U3.4 (P0.28); also elsewhere on the board
COL_6: U3.40 (P1.04); also elsewhere on the board
COL_7: U3.33 (P0.13); also elsewhere on the board
Debug_UART_Rx: U3.16 (P0.08)
Debug_UART_Tx: U3.14 (P0.06)
Encoder_A: U3.42 (P1.06); also elsewhere on the board
Encoder_B: U3.15 (P0.05); also elsewhere on the board
GND: C5.2, C6.1, C7.2, C8.2, SW2.1, U3.5 (GND), U3.21 (GND), U3.24 (GND); also elsewhere on the board
unnamed: C5.1, U3.11 (P0.00/XL1), Y1.2
unnamed: C6.2, U3.13 (P0.01/XL2), Y1.1
QMK_UART_Rx: U3.36 (P1.00)
QMK_UART_Tx: U3.38 (P1.02)
ROW_0: U3.10 (P0.30); also elsewhere on the board
ROW_1: U3.9 (P0.31); also elsewhere on the board
ROW_2: U3.8 (P0.29); also elsewhere on the board
ROW_3: U3.7 (P0.02); also elsewhere on the board
ROW_4: U3.6 (P1.13); also elsewhere on the board
ROW_5: U3.17 (P1.09); also elsewhere on the board
SWC: U3.39 (SWCLK); also elsewhere on the board
SWD: U3.37 (SWDIO); also elsewhere on the board
USB_D+: U3.31 (D+); also elsewhere on the board
USB_D-: U3.29 (D-); also elsewhere on the board
VDD: C7.1, R5.1, U3.19 (VDD), U3.23 (VDDH); also elsewhere on the board
~RESET: R5.2, SW2.2, U3.26 (P0.18/RST)



Board: 2 copper layers, 115.6 x 106.7 mm, 90 parts (61 on the bottom side), 63 nets.

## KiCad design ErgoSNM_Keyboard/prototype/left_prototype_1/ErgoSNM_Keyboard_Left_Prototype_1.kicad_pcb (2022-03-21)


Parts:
C1: 10uF; C_0201_0603Metric_Pad0.64x0.40mm_HandSolder
C2: 1uF; C_0201_0603Metric_Pad0.64x0.40mm_HandSolder
D1, D2, D3, D4, D5, D6, D7, D8, D9, D10, D11, D12, D13, D14, D15, D16, D17, D18, D19, D20, D21, D22, D23, D24: 1N4148; D_0603_1608Metric_Pad1.05x0.95mm_HandSolder
D25: 1N5819; D_1206_3216Metric_Pad1.42x1.75mm_HandSolder
J1: Conn_01x02; PinHeader_1x02_P2.54mm_Horizontal
J2: Conn_01x02; PinHeader_1x02_P2.54mm_Vertical
J3: Conn_01x02; JST_EH_B2B-EH-A_1x02_P2.50mm_Vertical
J4: Conn_01x06; PinHeader_1x06_P2.54mm_Vertical
J5: Conn_01x05; PinHeader_1x05_P2.54mm_Vertical
JP1: Jumper_2_Bridged; SolderJumper-2_P1.3mm_Open_TrianglePad1.0x1.5mm
KEY1: 00; MX_Switch_Gateron_socket_A
KEY2: 01; MX_Switch_Gateron_socket_A
KEY3: 02; MX_Switch_Gateron_socket_A
KEY4: 03; MX_Switch_Gateron_socket_A
KEY5: 04; MX_Switch_Gateron_socket_A
KEY6: 05; MX_Switch_Gateron_socket_A
KEY7: 10; MX_Switch_Gateron_socket_A
KEY8: 11; MX_Switch_Gateron_socket_A
KEY9: 12; MX_Switch_Gateron_socket_A
KEY10: 13; MX_Switch_Gateron_socket_A
KEY11: 14; MX_Switch_Gateron_socket_A
KEY12: 15; MX_Switch_Gateron_socket_A
KEY13: 20; MX_Switch_Gateron_socket_A
KEY14: 21; MX_Switch_Gateron_socket_A
KEY15: 22; MX_Switch_Gateron_socket_A
KEY16: 23; MX_Switch_Gateron_socket_A
KEY17: 24; MX_Switch_Gateron_socket_A
KEY18: 25; MX_Switch_Gateron_socket_A
KEY19: 30; MX_Switch_Gateron_socket_A
KEY20: 31; MX_Switch_Gateron_socket_A
KEY21: 32; MX_Switch_Gateron_socket_A
KEY22: 33; MX_Switch_Gateron_socket_A
KEY23: 34; MX_Switch_Gateron_socket_A
KEY24: 35; MX_Switch_Gateron_socket_A
M1: nRF51822_Core_board; Core51822
M2: Pro_Micro
M3: Adafruit_Bluefruit_LE_SPI_Friend; PinHeader_1x09_P2.54mm_Vertical
R1: 4.7k; R_0201_0603Metric_Pad0.64x0.40mm_HandSolder
R2: 10k; R_0201_0603Metric_Pad0.64x0.40mm_HandSolder
SW1: SW_Push; SW_Push_1P1T_NO_CK_KSC6xxJ
SW2: SW_2P3T; MSK-23D20-T
SWD1: Conn_01x04; PinHeader_1x04_P2.54mm_Horizontal
TRRS1: PJ-393_TRRS_8P; PJ-393
U1: TP4057; SOT-23-6_Handsoldering

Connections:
+3V3: J4.1, M1.33 (Vcc), M2.Vcc, SW2.7, SWD1.1, TRRS1.8 (Sa)
/2.4GHz_Enable: M1.6 (P0.06), R2.1, SW2.5
/CS_Bluefruit: M2.8 (D8A8/PB4), M3.4 (CS)
/CS_nRF5: J4.5, M1.4 (P0.04)
/Col_0: KEY1.1, KEY7.1, KEY13.1, KEY19.1, M1.20 (P0.20)
/Col_1: KEY2.1, KEY8.1, KEY14.1, KEY20.1, M1.21 (P0.21)
/Col_2: KEY3.1, KEY9.1, KEY15.1, KEY21.1, M1.22 (P0.22)
/Col_3: KEY4.1, KEY10.1, KEY16.1, KEY22.1, M1.23 (P0.23)
/Col_4: KEY5.1, KEY11.1, KEY17.1, KEY23.1, M1.24 (P0.24)
/Col_5: KEY6.1, KEY12.1, KEY18.1, KEY24.1, M1.25 (P0.25)
/IRQ_Bluefruit: M2.7 (D7/PE6), M3.5 (IRQ)
/MISO_Bluefruit: M2.14 (D14/PB3), M3.2 (MISO)
/MISO_nRF5: J4.4, M1.3 (P0.03), TRRS1.3 (R2a)
/MOSI_Bluefruit: M2.16 (D16/PB2), M3.3 (MOSI)
/MOSI_nRF5: J4.3, M1.2 (P0.02)
/RAW_Pro_Micro: C2.1, M2.RAW, SW2.3, U1.4 (Vcc)
/RST_Bluefruit: M2.4 (D4A6/PD4), M3.7 (RST/SWDIO)
/RST_Pro_Micro: J1.1, M2.RST (Reset), SW1.2
/Row_0: D1.1 (K), D2.1 (K), D3.1 (K), D4.1 (K), D5.1 (K), D6.1 (K), M1.15 (P0.15)
/Row_1: D7.1 (K), D8.1 (K), D9.1 (K), D10.1 (K), D11.1 (K), D12.1 (K), M1.16 (P0.16)
/Row_2: D13.1 (K), D14.1 (K), D15.1 (K), D16.1 (K), D17.1 (K), D18.1 (K), M1.17 (P0.17)
/Row_3: D19.1 (K), D20.1 (K), D21.1 (K), D22.1 (K), D23.1 (K), D24.1 (K), M1.18 (P0.18)
/Rx_nRF5: M1.11 (P0.11), M2.0 (D0/PD2)
/SCK_Bluefruit: M2.15 (D15/PB1), M3.1 (SCK)
/SCK_nRF5: J4.2, M1.1 (P0.01), TRRS1.2 (R1a)
/Tx_nRF5: M1.9 (P0.09), M2.1 (D1/PD3)
/Vcc_BATT: C1.1, D25.2 (A), J3.1, U1.3 (BAT)
/Vcc_Bluefruit: JP1.2 (B), M3.9 (VIN), SW2.8
GND: C1.2, C2.2, J1.2, J3.2, J4.6, M1.34 (GND), M2.GND0 (GND), M2.GND1 (GND), M2.GND2 (GND), M3.8 (GND), R1.2, R2.2, SW1.1, SWD1.4, TRRS1.1 (Ta), U1.2 (GND)
unnamed: D1.2 (A), KEY1.2
unnamed: D2.2 (A), KEY2.2
unnamed: D3.2 (A), KEY3.2
unnamed: D4.2 (A), KEY4.2
unnamed: D5.2 (A), KEY5.2
unnamed: D6.2 (A), KEY6.2
unnamed: D7.2 (A), KEY7.2
unnamed: D8.2 (A), KEY8.2
unnamed: D9.2 (A), KEY9.2
unnamed: D10.2 (A), KEY10.2
unnamed: D11.2 (A), KEY11.2
unnamed: D12.2 (A), KEY12.2
unnamed: D13.2 (A), KEY13.2
unnamed: D14.2 (A), KEY14.2
unnamed: D15.2 (A), KEY15.2
unnamed: D16.2 (A), KEY16.2
unnamed: D17.2 (A), KEY17.2
unnamed: D18.2 (A), KEY18.2
unnamed: D19.2 (A), KEY19.2
unnamed: D20.2 (A), KEY20.2
unnamed: D21.2 (A), KEY21.2
unnamed: D22.2 (A), KEY22.2
unnamed: D23.2 (A), KEY23.2
unnamed: D24.2 (A), KEY24.2
unnamed: D25.1 (K), SW2.1, SW2.4
unnamed: J2.1, U1.1 (CHRG)
unnamed: J2.2, U1.5 (STDBY)
unnamed: J5.1, M1.12 (P0.12)
unnamed: J5.2, M1.13 (P0.13)
unnamed: J5.3, M1.14 (P0.14)
unnamed: J5.4, M1.30 (P0.30)
unnamed: J5.5, M1.28 (P0.28)
unnamed: JP1.1 (A), SW2.6
unnamed: M1.31 (SWDIO/RESET), SWD1.3
unnamed: M1.32 (SWCLK), SWD1.2
unnamed: R1.1, U1.6 (PROG)

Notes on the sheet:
1/5: 2.4GHz 2/6: USB (Battery off) 4/8: Bluetooth



Board: 2 copper layers, 140.0 x 88.0 mm, 67 parts (37 on the bottom side), 65 nets.

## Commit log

2022-02-27 Add KiCad Sch and PCB Files
    [ErgoSNM_Keyboard_Left_Prototype_1.kicad_pcb, ErgoSNM_Keyboard_Left_Prototype_1.kicad_sch, ErgoSNM_Keyboard_Prototype_1.kicad_sch]
2022-02-27 Add footprint for Pro Micro
2022-02-28 Update Sch file
    [ErgoSNM_Keyboard_Left_Prototype_1.kicad_pcb, ErgoSNM_Keyboard_Left_Prototype_1.kicad_sch]
2022-03-21 Update PCB
    [ErgoSNM_Keyboard_Left_Prototype_1.kicad_pcb, ErgoSNM_Keyboard_Left_Prototype_1.kicad_sch]
2022-03-26 Add ErgoSNM prototype right side
    [ErgoSNM_Keyboard_Right_Prototype_1.kicad_pcb, ErgoSNM_Keyboard_Right_Prototype_1.kicad_sch]
2022-10-28 Update key-switches footprint library submodule
2022-10-28 Create new KiCad project
    [ErgoSNM_keyboard.kicad_pcb, ErgoSNM_keyboard.kicad_sch]
2022-10-28 Update sch
    [ErgoSNM_keyboard.kicad_pcb, ErgoSNM_keyboard.kicad_sch]
2022-10-30 Add mark
    [ErgoSNM_keyboard.kicad_pcb]
2022-11-01 Add EC56_rotary encoder KiCad project
    [EC56_rotary_encoder_pcb.kicad_pcb, EC56_rotary_encoder_pcb.kicad_sch]
2022-11-02 Update footprint
    [ErgoSNM_keyboard.kicad_pcb, ErgoSNM_keyboard.kicad_sch]
2022-11-02 Move 1N4148s away from key switches
    [ErgoSNM_keyboard.kicad_pcb]
2022-11-03 Update submodule for key switch footprint
2022-11-16 Move KiCad project
    [ErgoSNM_keyboard.kicad_sch]
2022-11-16 Move an rename prototype KiCad project
    [ErgoSNM_Keyboard_Left_Prototype_1.kicad_pcb, ErgoSNM_Keyboard_Left_Prototype_1.kicad_sch, ErgoSNM_Keyboard_Right_Prototype_1.kicad_pcb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]
2022-11-20 Create Rev2
    [RP2040.kicad_sch, key_matrix.kicad_sch, left.kicad_pcb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]
2022-11-21 Update rev2
    [RP2040.kicad_sch, key_matrix.kicad_sch, left.kicad_pcb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]
2022-11-25 Add logo
    [left.kicad_pcb]
2022-12-11 Update `Rev 1.1`
    [ErgoSNM_keyboard.kicad_sch]
2022-12-19 Update BOM, net, placement, etc.
    [RP2040.kicad_sch, key_matrix.kicad_sch, left.kicad_pcb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]
2022-12-20 Update RT9013 LDO placement and add logo
    [left.kicad_pcb]
2022-12-20 Copy left to right
    [ErgoSNM_right.kicad_pcb, ErgoSNM_right.kicad_sch, RP2040.kicad_sch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]
2023-01-20 Add thumb cluster PCB
    [thumb_cluster.kicad_pcb, thumb_cluster.kicad_sch]
2023-01-20 Update left
    [left.kicad_pcb]
2023-01-20 Update right hand schematic
    [ErgoSNM_right.kicad_pcb, ErgoSNM_right.kicad_sch, RP2040.kicad_sch]
2023-01-31 Update right PCB
    [ErgoSNM_right.kicad_pcb, ErgoSNM_right.kicad_sch, RP2040.kicad_sch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]
2023-01-31 Update silk and logo
    [ErgoSNM_right.kicad_pcb, left.kicad_pcb]
2023-01-31 Add vial 'Enter' key mark
    [ErgoSNM_right.kicad_pcb]
2023-02-01 Update logo
    [ErgoSNM_right.kicad_pcb, left.kicad_pcb]
2023-02-11 Add Rev2.0 plate KiCad files
    [ergosnm_v2.0_plate-1.kicad_pcb]
2023-02-26 Replace JST GH 1.25 connector with 0.5mm FPC
    [ErgoSNM_right.kicad_pcb, ErgoSNM_right.kicad_sch, left.kicad_pcb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]
2023-02-28 Update FPC connection and add additional LED LD2
    [ErgoSNM_right.kicad_pcb, ErgoSNM_right.kicad_sch]
2023-02-28 Add additional LED and upadrte LED position
    [left.kicad_pcb, left.kicad_sch]
2023-03-07 Add mount holes to plate
    [ergosnm_v2.0_plate-1.kicad_pcb]
2023-03-27 Update plate
    [ErgoSNM_right.kicad_pcb, ergosnm_plate.kicad_pcb, ergosnm_plate_thumb_cluster.kicad_pcb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]
2023-03-27 Add plate panel
    [ergosnm_plate_panel.kicad_pcb]
2023-04-29 Add footprint and symbol library path table
2023-07-04 Update key-switches.pretty git submodule URL
2023-07-17 Update footprint library submodule
2023-10-21 Add KiCad project for ErgoSNM Rev3
    [ErgoSNM_v3_right.kicad_pcb, ErgoSNM_v3_right.kicad_sch, key_matrix.kicad_sch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]
2023-11-14 Add LDO for USB
    [ErgoSNM_v3_right.kicad_pcb, ErgoSNM_v3_right.kicad_sch, mcu.kicad_sch]
2023-11-14 Add left hand
    [ErgoSNM_v3_left.kicad_pcb, ErgoSNM_v3_left.kicad_sch, ErgoSNM_v3_right.kicad_pcb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]
2023-11-14 Add receiver KiCad project
    [receiver.kicad_pcb, receiver.kicad_sch]
2023-11-14 Add key-matrix test pointes (2.54mm pin header)
    [ErgoSNM_v3_left.kicad_pcb, ErgoSNM_v3_left.kicad_sch, ErgoSNM_v3_right.kicad_pcb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]
2023-11-14 Update submodule
    Update submodule
    Update switch footprint
    [ErgoSNM_v3_left.kicad_pcb, ErgoSNM_v3_left.kicad_sch, ErgoSNM_v3_right.kicad_pcb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]
2023-11-14 Change license to CERN-OHL-P v2
    [ErgoSNM_right.kicad_pcb, ErgoSNM_right.kicad_sch, ErgoSNM_v3_left.kicad_pcb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]

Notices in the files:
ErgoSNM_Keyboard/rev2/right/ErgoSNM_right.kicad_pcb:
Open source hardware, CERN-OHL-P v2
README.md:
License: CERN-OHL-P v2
